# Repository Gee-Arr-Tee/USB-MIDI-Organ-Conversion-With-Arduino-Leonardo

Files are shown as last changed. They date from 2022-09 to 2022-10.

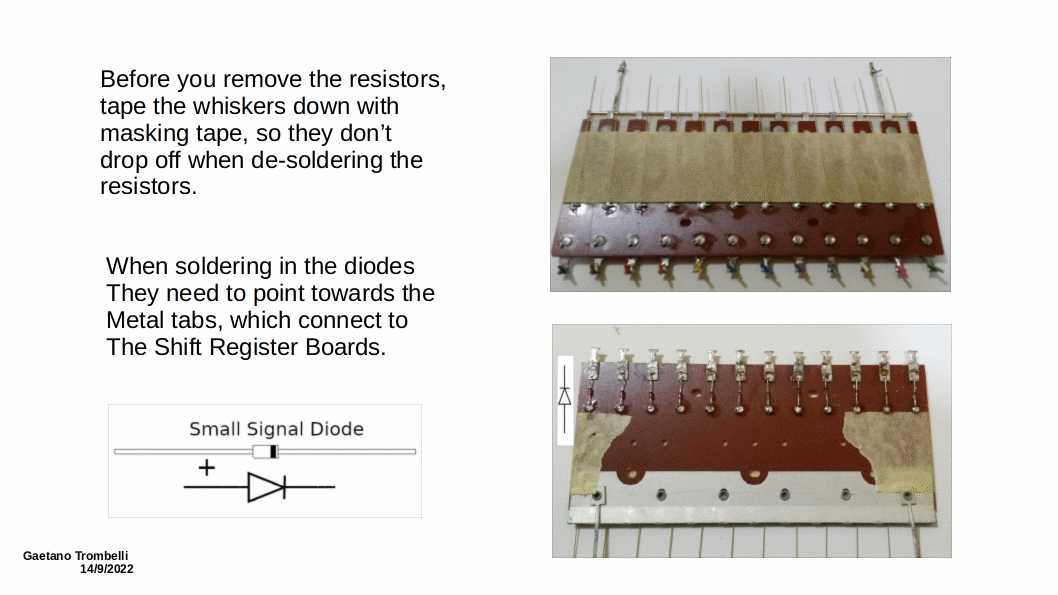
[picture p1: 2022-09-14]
res/HowTo_Connect_Baldwin_711_Key_Contacts/Baldwin_711_Key_Contacts_Modification_3of3.gif

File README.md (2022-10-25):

# USB-MIDI-Organ-Conversion-With-Arduino-Leonardo
How to Convert an Organ to a USB MIDI Controller to use with Hauptwerk / GrandOrgue or any DAW using 74HC165N Shift Registers.

All the Code and Eagle PCB and Schematic Files are provided, as well as connection diagrams and a Build of Materials (BOM).

Added the Gerber Files so anyone can get their own boards made.

Since an Arduino Leonardo does not have enough pins to control even a single 61 Note keyboard without using a diode matrix, shift registers are used as inputs for any extra pins required. 

A single board provides 32 Inputs which can be used for a Pedalboard and controlled by the Arduino with only 4 pins. 

Two boards can be linked to provide 64 Inputs, and controlled by only 4 pins also. 

Any object that can act as a switch can be used to trigger the Shift Registers and therefore play notes with, so it can be used on a hand made keyboard or group of switches etc., to construct a MIDI controller.

Using the boards to connect to an Arduino Leonardo, allows you to connect the devices directly to MIDI via the USB port, without having to change the bootloader. The Leonardo USB MIDI is detected by both Windows and Linux (if someone tries these on a Mac, I can update it on here). 

As a basis for for Project I used an old Baldwin 711 Organ, which has:
- Two 61 note keyboards.
- 25 Note Pedal Board.
- 30 Switches.
- Three Preset Buttons.
- One Analogue Pedal.

Using the Shift Registers PCBs, and this code with an Arduino Leonardo, it can handle:
 - Three 61 Note Keyboards.
 - 32 Note Pedal Board.
 - 32 Switches or Stops.
 - Nine Preset Buttons.
 - Two Analogue Pedals.

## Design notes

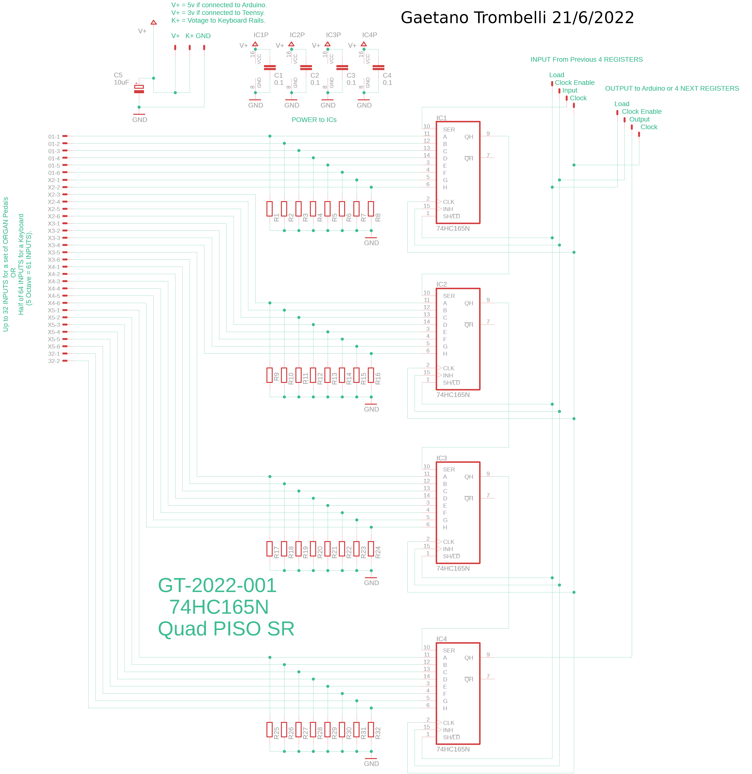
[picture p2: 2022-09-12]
res/Schematic_and_PCB_Images_and_BOM/GT-2022-001 Schematic.jpg

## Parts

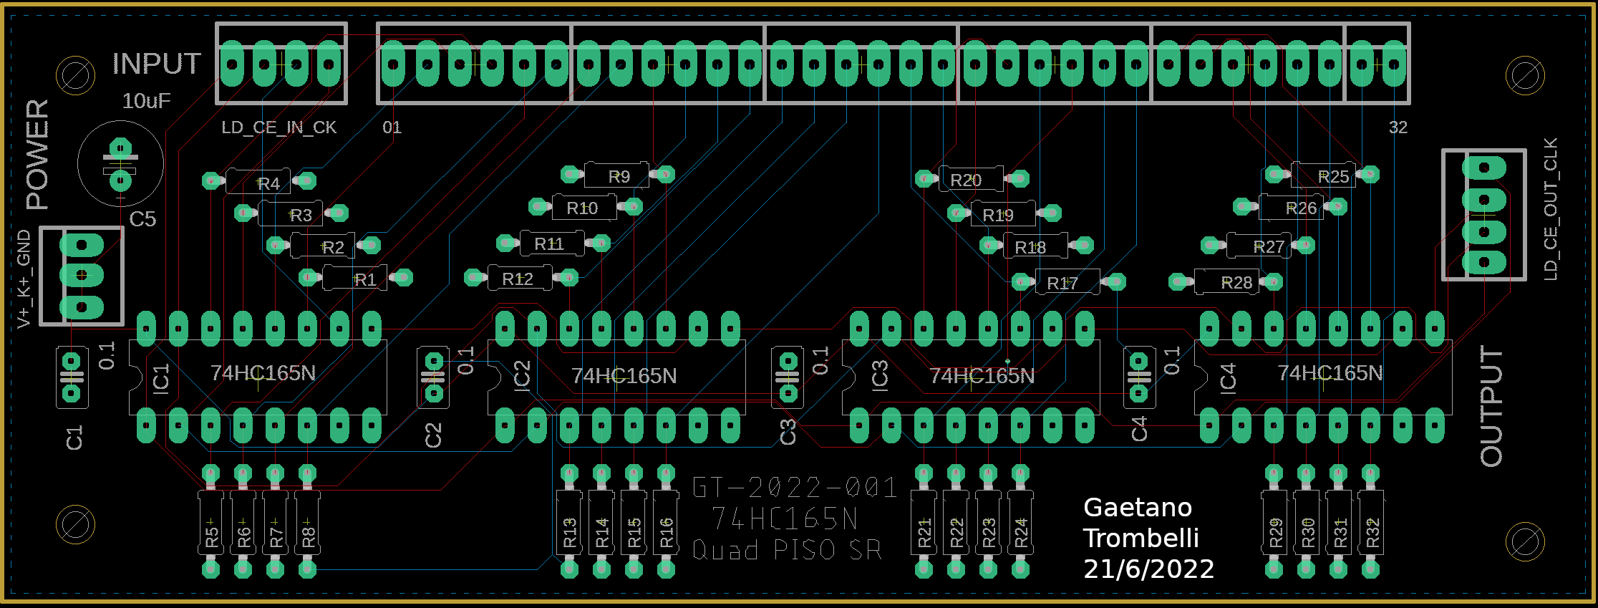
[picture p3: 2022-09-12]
res/Schematic_and_PCB_Images_and_BOM/GT-2022-001 Board.jpg

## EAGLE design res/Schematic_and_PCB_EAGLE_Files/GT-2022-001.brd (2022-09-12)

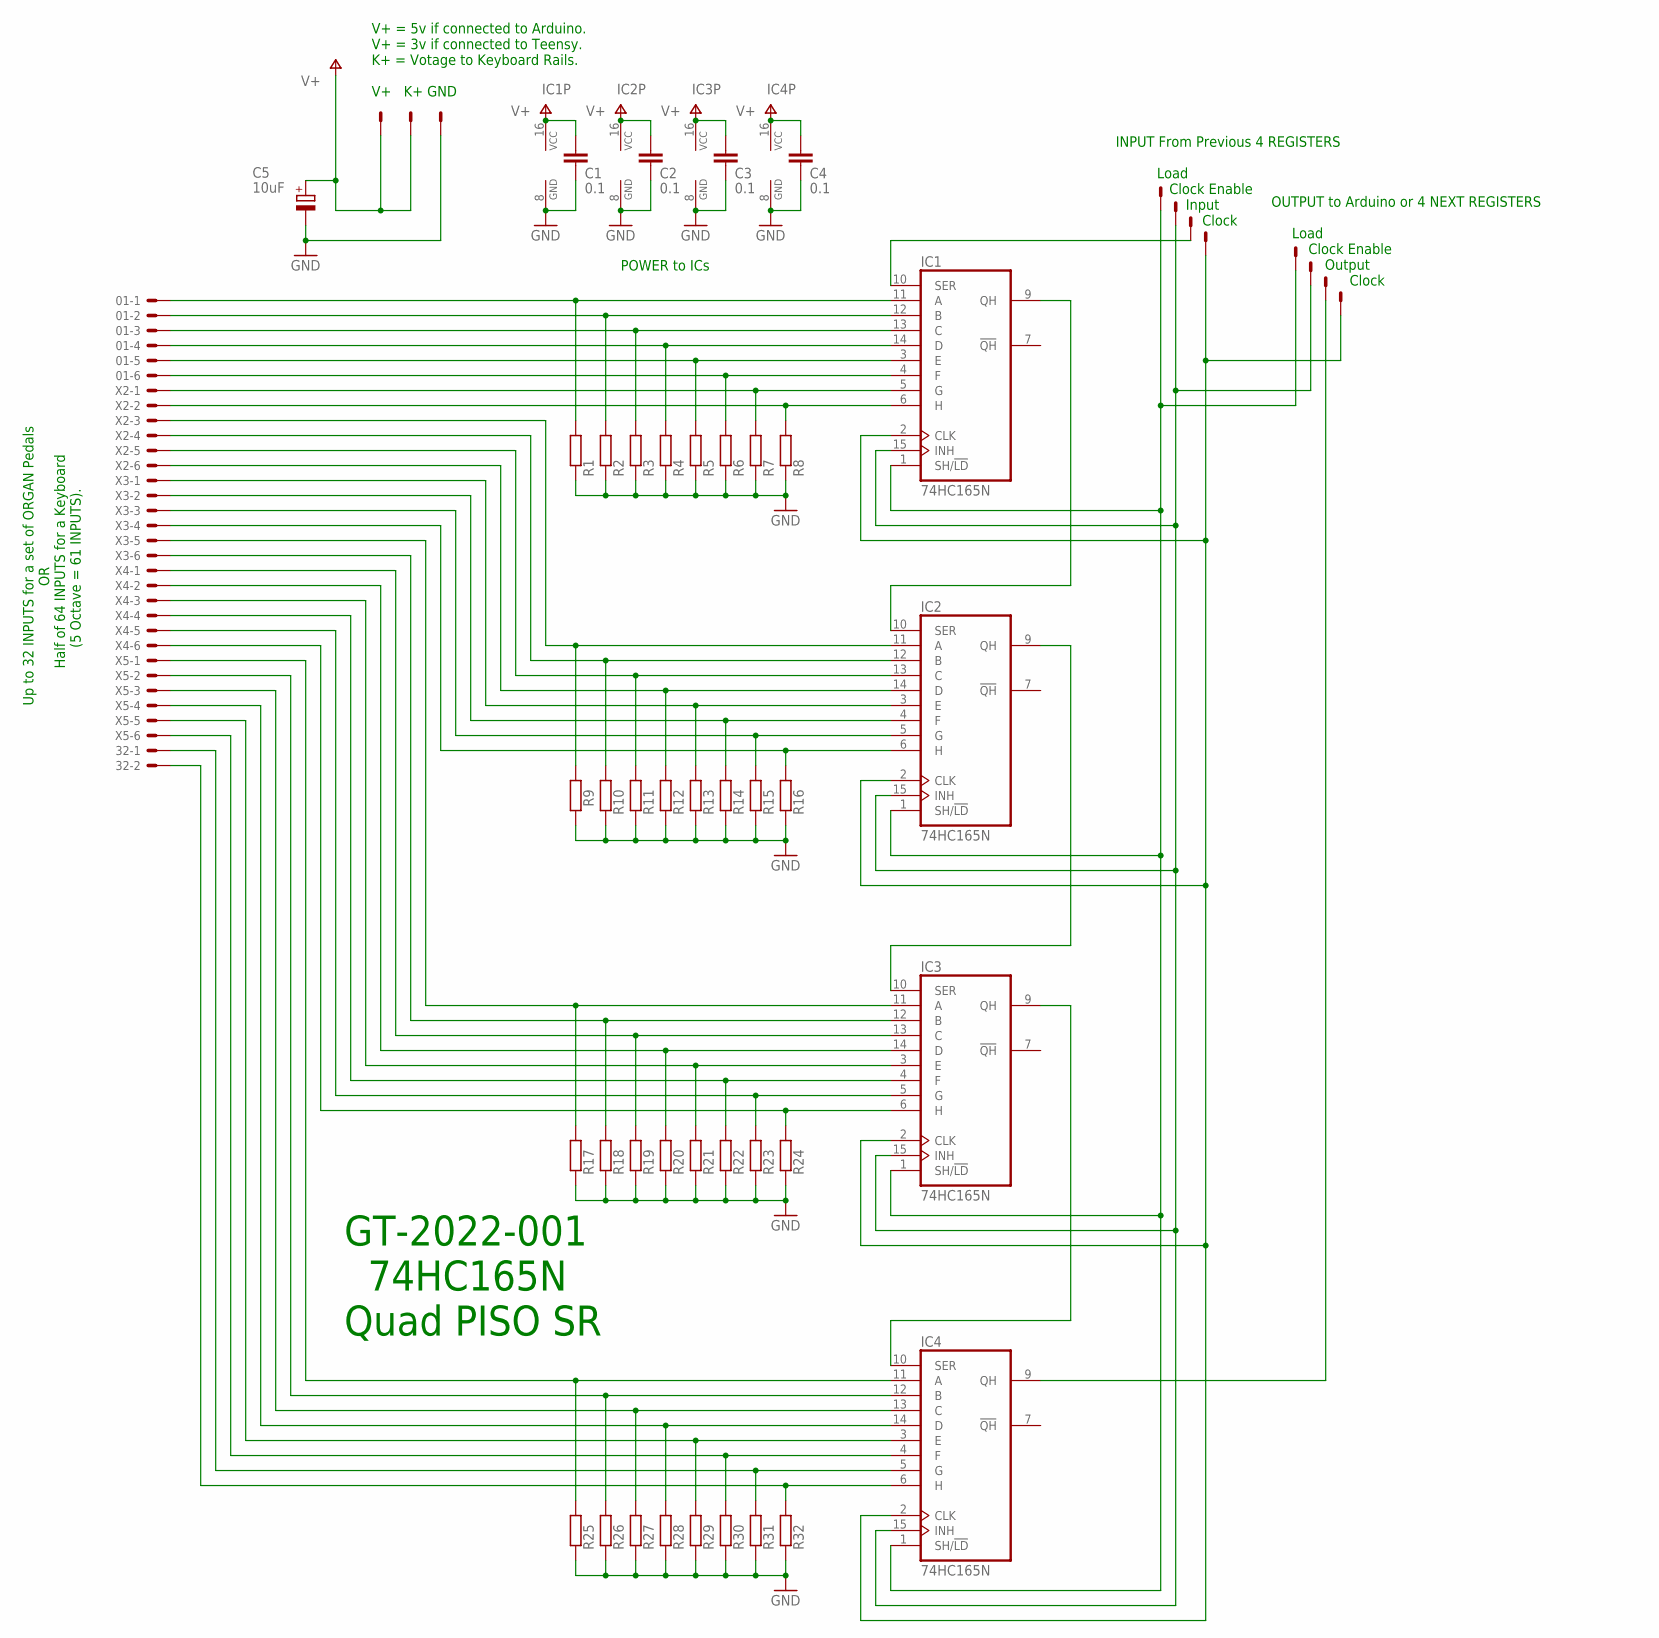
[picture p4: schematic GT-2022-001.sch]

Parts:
01: 22-23-2061
32: 22-23-2021
C1, C2, C3, C4: 0.1; C025-025X050
C5: 10uF; E2,5-7
IC1, IC2, IC3, IC4: 74HC165N; DIL16
LD_CE_IN_CK: 22-23-2041
LD_CE_OUT_CLK: 22-23-2041
R1, R2, R3, R4, R5, R6, R7, R8, R9, R10, R11, R12, R13, R14, R15, R16, R17, R18, R19, R20, R21, R22, R23, R24, R25, R26, R27, R28, R29, R30, R31, R32: R-EU_0204/7; 0204/7
V+_K+_GND: 22-23-2031
X2, X3, X4, X5: 22-23-2061

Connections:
GND: C1.2, C2.2, C3.2, C4.2, C5.-, IC1.8 (GND), IC2.8 (GND), IC3.8 (GND), IC4.8 (GND), R1.1, R2.1, R3.1, R4.1, R5.1, R6.1, R7.1, R8.1, R9.1, R10.1, R11.1, R12.1, R13.1, R14.1, R15.1, R16.1, R17.1, R18.1, R19.1, R20.1, R21.1, R22.1, R23.1, R24.1, R25.1, R26.1, R27.1, R28.1, R29.1, R30.1, R31.1, R32.1, V+_K+_GND.3
unnamed: IC1.5 (G), R7.2, X2.1
unnamed: 01.6, IC1.4 (F), R6.2
unnamed: 01.5, IC1.3 (E), R5.2
unnamed: 01.4, IC1.14 (D), R4.2
unnamed: 01.3, IC1.13 (C), R3.2
unnamed: 01.2, IC1.12 (B), R2.2
unnamed: 01.1, IC1.11 (A), R1.2
unnamed: IC2.6 (H), R16.2, X3.4
unnamed: IC4.4 (F), R30.2, X5.6
unnamed: IC3.12 (B), R18.2, X3.6
unnamed: IC3.11 (A), R17.2, X3.5
unnamed: IC4.14 (D), R28.2, X5.4
unnamed: IC1.1 (SH/!LD), IC2.1 (SH/!LD), IC3.1 (SH/!LD), IC4.1 (SH/!LD), LD_CE_IN_CK.1, LD_CE_OUT_CLK.1
unnamed: IC1.2 (CLK), IC2.2 (CLK), IC3.2 (CLK), IC4.2 (CLK), LD_CE_IN_CK.4, LD_CE_OUT_CLK.4
unnamed: IC1.10 (SER), LD_CE_IN_CK.3
unnamed: IC4.9 (QH), LD_CE_OUT_CLK.3
unnamed: IC4.11 (A), R25.2, X5.1
unnamed: IC1.6 (H), R8.2, X2.2
unnamed: IC1.9 (QH), IC2.10 (SER)
unnamed: IC2.9 (QH), IC3.10 (SER)
unnamed: IC1.15 (INH), IC2.15 (INH), IC3.15 (INH), IC4.15 (INH), LD_CE_IN_CK.2, LD_CE_OUT_CLK.2
unnamed: IC3.9 (QH), IC4.10 (SER)
unnamed: IC2.5 (G), R15.2, X3.3
unnamed: 32.1, IC4.5 (G), R31.2
unnamed: IC4.3 (E), R29.2, X5.5
unnamed: IC4.13 (C), R27.2, X5.3
unnamed: IC4.12 (B), R26.2, X5.2
unnamed: IC2.4 (F), R14.2, X3.2
unnamed: IC3.6 (H), R24.2, X4.6
unnamed: IC2.3 (E), R13.2, X3.1
unnamed: IC2.14 (D), R12.2, X2.6
unnamed: IC2.13 (C), R11.2, X2.5
unnamed: 32.2, IC4.6 (H), R32.2
unnamed: IC2.12 (B), R10.2, X2.4
unnamed: IC2.11 (A), R9.2, X2.3
unnamed: IC3.5 (G), R23.2, X4.5
unnamed: IC3.3 (E), R21.2, X4.3
unnamed: IC3.14 (D), R20.2, X4.2
unnamed: IC3.13 (C), R19.2, X4.1
unnamed: IC3.4 (F), R22.2, X4.4
V+: C1.1, C2.1, C3.1, C4.1, C5.+, IC1.16 (VCC), IC2.16 (VCC), IC3.16 (VCC), IC4.16 (VCC), V+_K+_GND.1, V+_K+_GND.2

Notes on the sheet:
INPUT From Previous 4 REGISTERS Load Clock Enable Input Clock
Up to 32 INPUTS for a set of ORGAN Pedals OR Half of 64 INPUTS for a Keyboard (5 Octave = 61 INPUTS).
V+ = 5v if connected to Arduino. V+ = 3v if connected to Teensy. K+ = Votage to Keyboard Rails. V+ K+ GND
OUTPUT to Arduino or 4 NEXT REGISTERS Load Clock Enable Output Clock
POWER to ICs
GT-2022-001 74HC165N Quad PISO SR

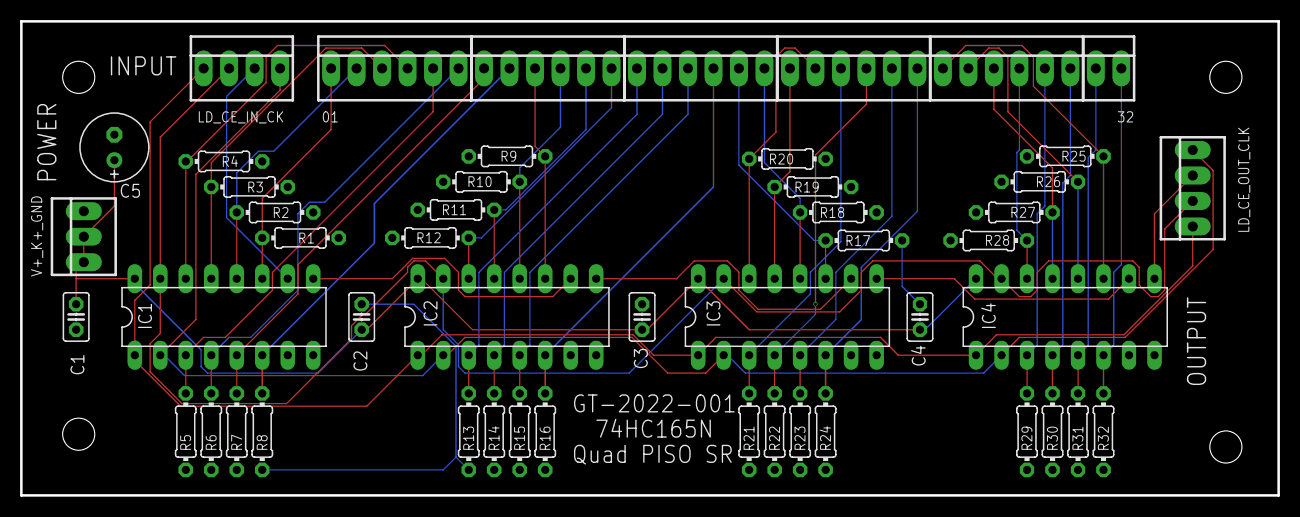
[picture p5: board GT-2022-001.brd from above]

Board: 2 copper layers, 125.3 x 47.2 mm, 50 parts (0 on the bottom side), 42 nets.

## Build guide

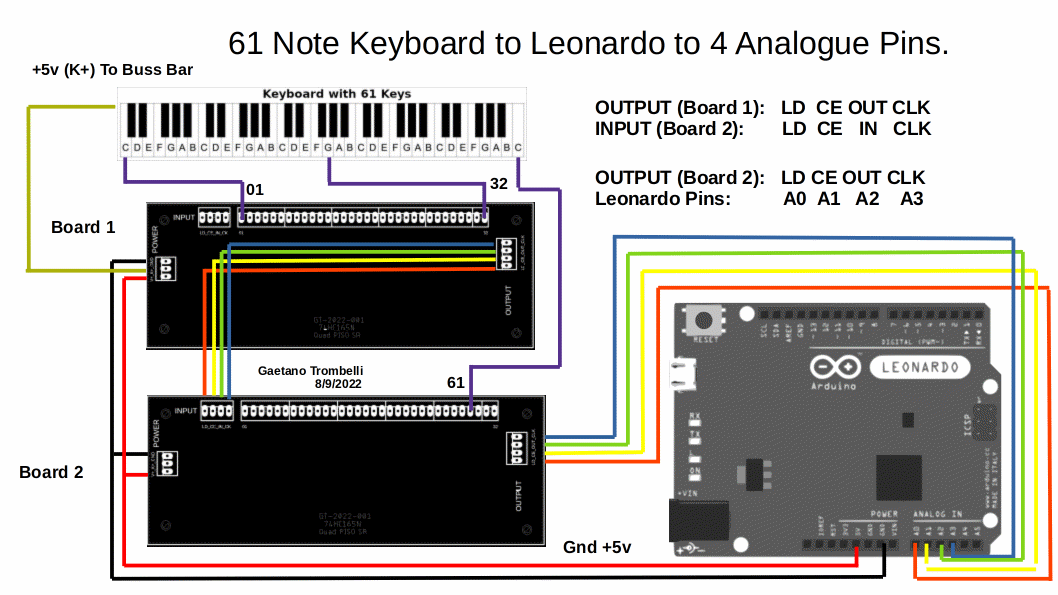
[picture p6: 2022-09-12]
res/HowTo_Use_The_ShiftRegister_Boards/61_Key_Keyboard_using_4_Analogue_Pins.gif

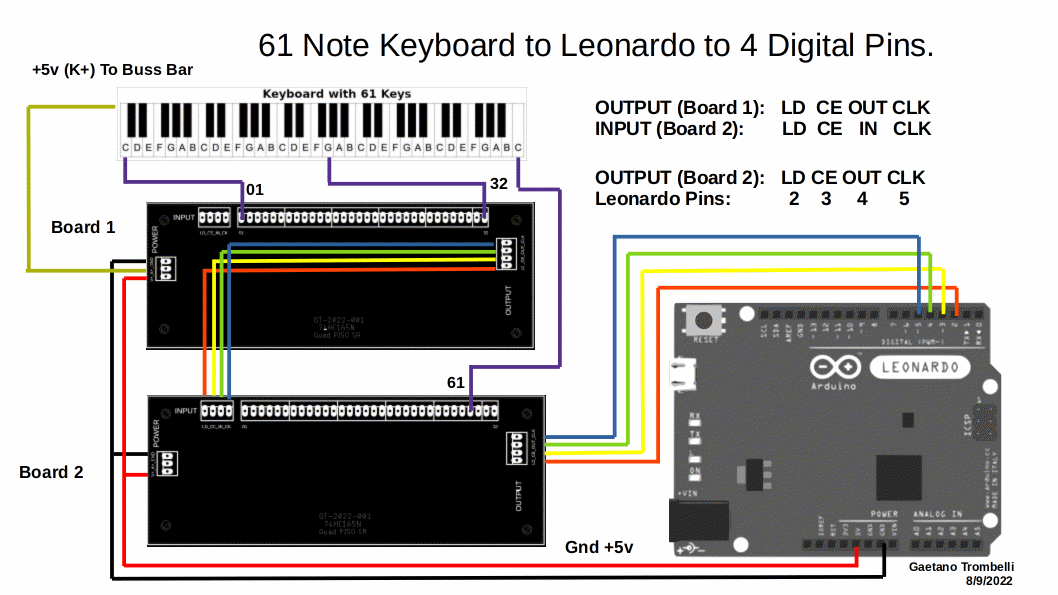
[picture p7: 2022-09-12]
res/HowTo_Use_The_ShiftRegister_Boards/61_Key_Keyboard_using_4_Digital_Pins.gif

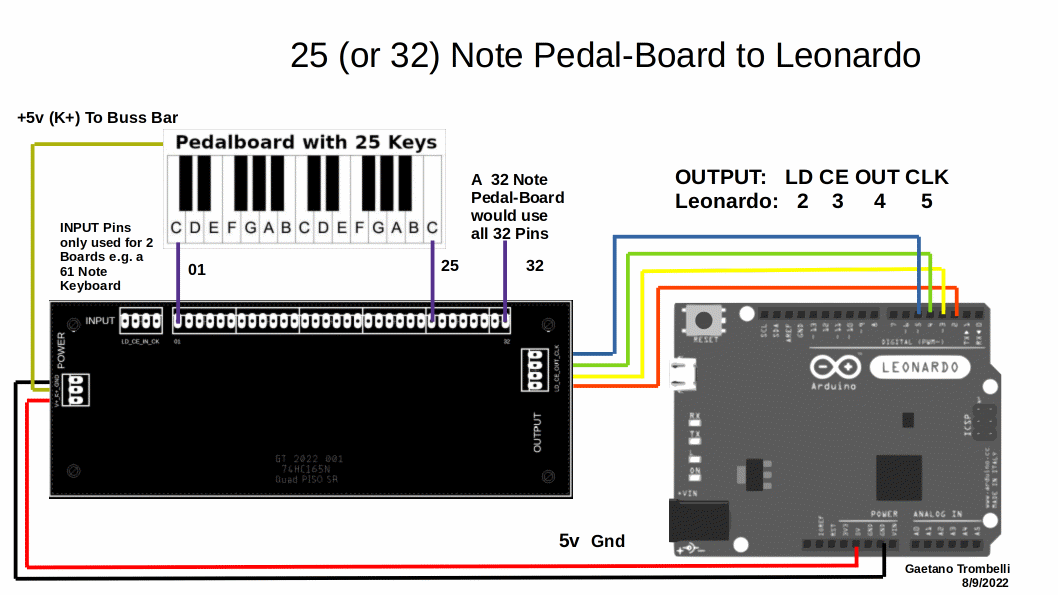
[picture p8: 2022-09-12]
res/HowTo_Use_The_ShiftRegister_Boards/32_Note_Pedalboard_using_4_Digital_Pins.gif

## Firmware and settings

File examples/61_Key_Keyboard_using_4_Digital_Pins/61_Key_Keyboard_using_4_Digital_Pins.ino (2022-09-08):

/* 
 * Title:   61_Key_Keyboard_using_4_Digital_Pins
 * Author:  Gaetano Trombelli
 * Date:    8/9/2022
 * Description: Using 8 x 74HC165N Shift Registers to connect a 61 key 
 * keyboard to an Arduino Leonardo to make a MIDI Keyboard Controller, 
 * using only 4 DIGITAL Pins.
 * You could in fact use anything to switch an input:
 * +5v --> to any shift register pin will trigger a note (see schematic).     
 */ 


// ============================================================
//                     Libraries to include
// ============================================================
/* 
 *  Shift Register Library to use with 74HC165N Shift Registers
 *  Reference:
 *  https://github.com/InfectedBytes/ArduinoShiftIn
 *  Adding: place in....libraries/ShiftIn/ShiftIn.h
 */
#include "ShiftIn.h" // 74HC165N Shift Register Library
/* 
 *  MIDI USB Library required for Arduino ATmega32U4 
 *  compatible for example an Arduino Leonardo.
 *  References:
 *  https://github.com/arduino-libraries/MIDIUSB
 *  https://www.arduino.cc/reference/en/libraries/midiusb/  
 *  Adding: Sketch > Include Library > Add .ZIP Library 
 */
#include "MIDIUSB.h" // ATmega32U4 (Leonardo) MIDI Library

//=======================================================================
//                    Variable Declarations
//=======================================================================
/*  
 *  Shift Registers needed to connect a 61 Note Keyboard:
 *  Need (64 Inputs = '8' x 8-Input Shift Registers). 
 *  ShiftIn<n> <NAME> => ShiftIn object called 'NAME' with 'n'      
 *  74HC165N Shift Registers Daisy Chained. 
 *  e.g., KBoard using 8 shift registers, and using
 *  61 out of 64 Inputs for KBoard leaves 3 spare Inputs.
*/
ShiftIn<8> KBoard;

//  =================================================          
//          MIDI Variable Declarations
//  =================================================  
/*  
 *  Declaring Channels and lowest Notes here,
 *  allows you to reallocate a channel or key
 *  range for a keyboard easily.
 *  -------------------------------------------------
 *  Since MIDI Channels are based on Binary Numbers
 *  0000 = 0 = Channel 1 to 1111 = 15 = Channel 16 
 *  To allocate a Channel 'n': use the number n-1,  
 *  e.g., For Channel 3, use n-1 = 2.
*/
//  =================================================          
//            MIDI Channel Declarations
//  ================================================= 
const byte midiChannelKBoard = 0;  // MIDI channel = (1)

/*  
 *  The note here is the Lowest note to start from:
 *  Most Keyboards start at C, so:
 *  For Reference: A 61 Key Keyboard:
 *  The range is usually      C(2) to  C(7)
 *  equivalent to MIDI NOTES: 36   to  96
 *  Pressing the Lowest  C(2) outputs MIDI Note 36
 *  Pressing the next note C#(2) outputs MIDI Note 37
 *  Pressing the Highest C(7) outputs MIDI Note 96
 *  C(1) = 24, C(2) = 36, C(3) = 48, C(4) = 60 (Middle C) etc.
 *  ---------------------------------------------------------
 *  Setting the start Notes to 36 will give the range above
 *  To make the KBoard an octave higher:
 *  const byte lowestNoteKBoard = 48  (+12 notes)
 *  To make the Pedal Board an octave lower:
 *  const byte lowestNoteKBoard = 24  (-12 notes)
 */
//  =================================================          
//       Lowest MIDI Note for Keyboards & Pedals 
//  ================================================= 
const byte lowestNoteKBoard = 36;


//======================================================================
// Set the Keyboard 'fixed' MIDI Velocities
//======================================================================
/*  
 *  'velocityStandard' = 100 => Each key sends this Velocity when played.
 *  0 <= Velocity <= 127, NORMAL = 64, MAXIMUM = 127. 
 *  If you always want to send the MAXIMUM velocity possible,
 *  then just change this to velocityStandard = 127
 *  'velocityZero = 0' => ZERO Velocity sent when note is released 
*/
const byte velocityStandard = 100;
const byte velocityZero = 0;


void setup() { // Run this once.
//===============================================================
//      Setup MIDI Baud Rate: Use 115200 for USB MIDI
//===============================================================
  Serial.begin(115200);
  
// ===============================================================     
//  Declare the Pins used by the Arduino Leonardo      
//  to controll the 74HC165N Shift Registers
// =============================================================== 
/*  
 *  74HC165N pins: PL-pin1,  CE-pin15,       Q7-pin9, CP-pin2
 *  Declare pins:  pLoadPin, clockEnablePin, dataPin, clockPin
 *  --------------------------------------------------------------
 *  Connects to: 
 *  74HC165N Pins (1, 15, 9, 2)
 *  Leonardo Pins (2, 3,  4, 5)
 */
KBoard.begin(2, 3, 4, 5);
}


void loop() { // Main Program Loop
/* 
 * Constantly checks to see if a key has changed, and if true 
 * the executes the function 'triggerMidiNotesKBoard();'
 */
  if(KBoard.update()) { // If there is a change in KBoard
            triggerMidiNotesKBoard(); // Then execute this function
    }
          
	delay(1); // requirement of ShiftIn Library.
  } 
  
 
void triggerMidiNotesKBoard() { 
//==============================================================
// If a change is detected in the 61 key (KBoard) Keyboard, 
// then this sends the corresponding note to MIDI Channel 1
//==============================================================

byte noteKBoard;

  for(byte i = 0; i < KBoard.getDataWidth(); i++) { 

    if (KBoard.pressed(i) == true) { // KBoard key is Pressed
      noteKBoard = (i + lowestNoteKBoard);
      noteOn(midiChannelKBoard, noteKBoard, velocityStandard);
      MidiUSB.flush();
    } 
 
    if (KBoard.released(i) == true) { // KBoard key is Released
      noteKBoard = (i + lowestNoteKBoard);
      noteOff(midiChannelKBoard, noteKBoard, velocityZero);
      MidiUSB.flush();
    } 
 
  } 
   
} 

//====================================================================
//     -----     ATmega32U4 (Leonardo) MIDIUSB Library     -----
//====================================================================

//--------------------------------------------------------------------
//                        Note ON / Note OFF
//--------------------------------------------------------------------
// First parameter is the event type (0x09 = note on, 0x08 = note off).
// Second parameter is note-on/note-off, combined with the channel.
// Channel can be anything between 0-15. Typically reported to the user as 1-16.
// Third parameter is the note number (48 = middle C).
// Fourth parameter is the velocity (64 = normal, 127 = fastest).

void noteOn(byte channel, byte pitch, byte velocity) {
  midiEventPacket_t noteOn = {0x09, 0x90 | channel, pitch, velocity};
  MidiUSB.sendMIDI(noteOn);
} // noteOn

void noteOff(byte channel, byte pitch, byte velocity) {
  midiEventPacket_t noteOff = {0x08, 0x80 | channel, pitch, velocity};
  MidiUSB.sendMIDI(noteOff);
} // noteOff

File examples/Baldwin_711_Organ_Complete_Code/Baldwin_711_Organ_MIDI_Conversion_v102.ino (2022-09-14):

/* 
 * Title:   Baldwin_711_Organ_MIDI_Conversion_v102
 * Author:  Gaetano Trombelli
 * Date:    13/9/2022
 * Description: Using 74HC165N Shift Registers to connect a 
 * Baldwin 711 Organ to an Arduino Leonardo to use with 
 * standard MIDI software via USB. It has been tested with,
 * Hauptwek, GrandOrgue, Ableton Live and other DAWs, 
 * and works like a standalone MIDI Workstation.  
 * 
 *  The Organ has:
 *   - Two 61 note keyboards.
 *   - 25 Note Pedal Board.
 *   - 30 Switches.
 *   - Three Preset Buttons.
 *   - One Analogue Pedal.
 */ 

// ============================================================
//                     Libraries to include
// ============================================================
/* 
 *  'ShiftIn.h' Shift Register Library to use with standard 
 *  74HC165N PISO Shift Registers.
 *  Reference:
 *  https://github.com/InfectedBytes/ArduinoShiftIn
 *  Adding: place in....libraries/ShiftIn/ShiftIn.h
 */
#include "ShiftIn.h" // 74HC165N Shift Register Library
/* 
 *  'MIDIUSB.h' MIDI USB Library required for Arduino ATmega32U4 
 *  compatibles, for example an Arduino Leonardo.
 *  References:
 *  https://github.com/arduino-libraries/MIDIUSB
 *  https://www.arduino.cc/reference/en/libraries/midiusb/  
 *  Adding: Sketch > Include Library > Add .ZIP Library 
 */
#include "MIDIUSB.h" // ATmega32U4 (Leonardo) MIDI Library

//========================================================================
//                    Variable Declarations
//========================================================================
/*  
 *  Shift Registers are needed to connect a Baldwin 711 to an Arduino Leonardo
 *  as it does not have enough pins to connect multiple keyboards, even
 *  if you were using diode matrices.
 *  
 *  We need for A Baldwin 711:  
 *  - Upper Swell 61 Note Keyboard:  ('8' x 8 = 64 Input Shift Registers). 
 *  - Three Preset Switches:(Use the 3 left over from the Swell keyboard).
 *  - Lower Great 61 Note Keyboard:  ('8' x 8 = 64 Input Shift Registers). 
 *  The 25 Note Pedal Board and the 30 Rocker Switches need 4 Shift 
 *  Registers each. In the code below however they are combined and use 
 *  8 Shift Registers and therefore only 4 Leonardo pins. This was done 
 *  in order to keep 4 pins free in case someone wanted to add another 
 *  61 Note Keyboard. See '61_Key_Keyboard_using_4_Analogue_Pins' in 
 *  the examples folder.
 *  - A 25 or 32 Note Pedal Board:   ('4' x 8 = 32 Input Shift Registers). 
 *  - 30 Rocker Switches:            ('4' x 8 = 32 Input Shift Registers). 
 *  - Volume / Swell Pedal:          (1 Analog Input).
 *  If you add a third keyboard, there is then one Analogue pin left,
 *  for a second Volume / Swell Pedal.
 *  ----------------------------------------------------------------------
 *  To use the ShiftIn.h Library, ShiftIn<n> <NAME> => 
 *  ShiftIn object called 'NAME' with 'n' 74HC165N Shift Registers 
 *  Daisy Chained n = 8 Maximum. Using the maximum of 8 for the organ
 *  means that I can use the minimum of 3 x 4 pins = 12 pins. 
 *  Just to be clear, 61/64 means 61 out of 64 pins available.
*/
ShiftIn<8> Swell;      // 61/64 Key Upper (Swell) Keyboard -+ (3 spare)
                       // 3 /64 Preset Buttons (Under Swell Keyboard)                           
ShiftIn<8> Great;      // 61/64 Key Lower (Great) Keyboard -+ (3 spare)
ShiftIn<8> PedalsStops;// 25/32 Key Pedalboard -------------+ (7 spare)
                       // 30/32 Stops or Buttons -----------+ (2 spare)

//  =================================================          
//          MIDI Variable Declarations
//  =================================================  
/*  
 *  Declaring Channels and lowest Notes here,
 *  allows you to reallocate a channel or key
 *  range for a keyboard easily.
 *  -------------------------------------------------
 *  Since MIDI Channels are based on Binary Numbers
 *  0000 = 0 = Channel 1 to 1111 = 15 = Channel 16 
 *  To allocate a Channel 'n': use the number n-1,  
 *  e.g., For Channel 3, use n-1 = 2.
 *  ------------------------------------------------------------
 *  Note: uint8_t = 'byte' = 8bit unsigned (non-negative) 
 *  integer, where    0 <= uint8_t <= 255
 *  Makes it easier to use this code for a different Arduino etc.
*/
//  =================================================          
//            MIDI Channel Declarations
//  ================================================= 
const uint8_t midiChannelSwell = 0;  // MIDI channel = (1)
const uint8_t midiChannelGreat = 1;  // MIDI channel = (2)
const uint8_t midiChannelPedals = 2; // MIDI channel = (3)
const uint8_t midiChannelStops = 3;  // MIDI channel = (4)
const uint8_t midiChannelPresets = 3;// MIDI channel = (4) also

/* 
 *  The note here is the Lowest note to start from:
 *  Most Keyboards start at C, so:
 *  For Reference: A 61 Note Keyboard:
 *  The range is usually      C(2) to  C(7)
 *  equivalent to MIDI NOTES: 36   to  96
 *  Pressing the Lowest  C(2) outputs MIDI Note 36
 *  Pressing the next note C#(2) outputs MIDI Note 37
 *  Pressing the Highest C(7) outputs MIDI Note 96
 *  C(1) = 24, C(2) = 36, C(3) = 48, C(4) = 60 (Middle C) etc.
 *  ---------------------------------------------------------
 *  Setting the start Notes to 36 will give the range above
 *  To make the Great an octave higher:
 *  const uint8_t lowestNoteGreat = 48  (+12 notes)
 *  To make the Pedal Board an octave lower:
 *  const uint8_t lowestNotePedals = 24 (-12 notes)
 */
//  =================================================          
//       Lowest MIDI Note for Keyboards & Pedals 
//  ================================================= 
const uint8_t lowestNoteSwell = 36;
const uint8_t lowestNoteGreat = 36;
const uint8_t lowestNotePedals = 36;

//======================================================================
// Set the Keyboard and Pedal Board 'fixed' MIDI Velocities
//======================================================================
/* 
 *  'velocityStandard' = 100 => Each key or Pedal sends this Velocity always.
 *  0 <= Velocity <= 127, NORMAL = 64, MAXIMUM = 127. 
 *  If you always want to send the MAXIMUM velocity possible,
 *  then just change this to velocityStandard = 127
 *  'velocityZero = 0' => ZERO Velocity sent when note is released 
*/
const uint8_t velocityStandard = 100;
const uint8_t velocityZero = 0;
/*
 *  Volume MIDI Control Change = 7, 
 *  MIDI CC List from: 
 *  https://professionalcomposers.com/midi-cc-list/
 *  Note that: uint16_t is used for volumePedal as Analogue read gives, 
 *  a value from 0 to 1023 = 1024 values, i.e. larger than uint8_t
*/
const uint8_t volPedalChannel = 0; // MIDI channel (1)
const uint8_t volPedalCC = 7; // Volume MIDI CC to be used = 7
uint16_t volPedalValue = 0;     // Current Volume Value
uint16_t volPedalPrevValue = 0; // Previous Volume Value
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

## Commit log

2022-09-12 Add files via upload
    How to Connect Keyboards, Pedalboards and Potentiometers to a standard Buss Bar and then to the Shift Register PCBs.
2022-09-12 Add files via upload
    Quad 74HC165N Shift Register Boards, created with Eagle v9.6.2
    The Boards can be used with the Arduino Leonardo Code provided, to make a keyboard or MIDI Controller from anything that acts as a switch.
    [GT-2022-001.brd, GT-2022-001.sch]
2022-09-12 Add files via upload
    The Schematic and PCB Images of the Quad 74HC165N Shift Register Board, including the Build of Materials with images of the Components.
2022-10-25 Create Schematic_and_PCB_GERBER_Files
